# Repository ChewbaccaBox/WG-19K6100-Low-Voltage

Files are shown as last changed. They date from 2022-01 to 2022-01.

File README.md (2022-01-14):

# WG-19K6100-Low-Voltage
My version of the low voltage replacement board for the 6100 monitor.\
Larger / Through-hole parts provide beter thermals.\
Adjustable voltage range = +/- 23.5v - 28.5v \
&nbsp;

**BILL OF MATERIALS** :\
Includes example digikey item #'s

**1 * LM317 ( TO-220 pkg.)**\
&nbsp;&nbsp;&nbsp;&nbsp; DGK: LM317TG \
**1 * LM337 ( TO-220 pkg.)**\
&nbsp;&nbsp;&nbsp;&nbsp; DGK: LM3137TG \
**2 * 1k Trimmer Pot (PCB can fit both '.' and ... pin types, 0.1" spacing)**\
&nbsp;&nbsp;&nbsp;&nbsp; DGK: 500E-0331 or DGK:3306W-1-102\
**6 * 1N4007 Diode**\
**4 * 2.2uF 50V Capacitor**\
**2 * 10uF 50V Capacitor**\
**2 * 240 Ohm Resistor 1/4W**\
**4 * 4.5k Ohm Resistor 1/4W**\
**5 * WIRES TO RAISE PCB OVER BOARD**

**(OPTIONAL) 2 * TO-220 Compact Heatsink + Insulator/Thermal Pad** \
&nbsp;&nbsp;&nbsp;&nbsp; DGK: 577102B00000G + SP400-0.007-00-54 \
&nbsp;

**TESTING STATUS:**

Multiple installed and working in revisions P314 and P327.\
The filter capicators of the deflection board are closer to the connector on revision P327, so it is a little tighter, but will still work.

**INSTALLATION INSTRUCTIONS:**

To be written... Stay tuned!

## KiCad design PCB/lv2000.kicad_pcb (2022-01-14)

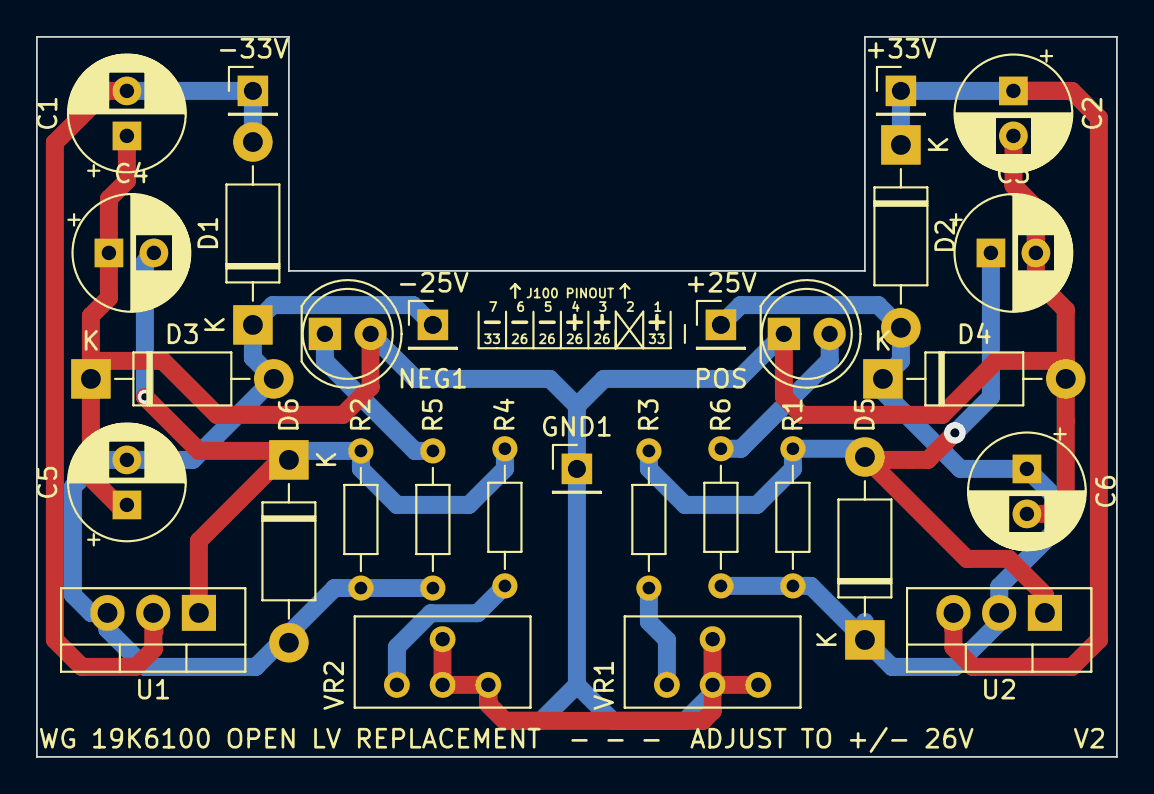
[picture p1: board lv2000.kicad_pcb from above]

Board: 2 copper layers, 60.0 x 40.0 mm, 29 parts (0 on the bottom side), 11 nets.

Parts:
+25V, +33V: Conn_01x01_Male; PinHeader_1x01_P2.54mm_Vertical
-25V, -33V: Conn_01x01_Male; PinHeader_1x01_P2.54mm_Vertical
C1, C2, C3, C4, C5, C6: CP; CP_Radial_D6.3mm_P2.50mm
D1, D2, D3, D4, D5, D6: D; D_DO-41_SOD81_P10.16mm_Horizontal
GND1: Conn_01x01_Male; PinHeader_1x01_P2.54mm_Vertical
NEG1: LED; LED_D5.0mm_Clear
POS: LED; LED_D5.0mm_Clear
R1, R2, R3, R4, R5, R6: R; R_Axial_DIN0204_L3.6mm_D1.6mm_P7.62mm_Horizontal
U1: LM337_TO220; TO-220-3_Vertical
U2: LM317_TO-220; TO-220-3_Vertical
VR1, VR2: R_POT; Potentiometer_Bourns_3386C_Horizontal

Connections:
GND: C1.1, C2.2, C3.2, C4.1, C5.1, C6.2, D3.1, D4.2, GND1.1, NEG1.2, POS.1, VR1.2, VR1.3, VR2.2, VR2.3
unnamed: +25V.1, C6.1, D2.2, D4.1, D5.1, R1.1, R6.1, U2.2
unnamed: +33V.1, C2.1, D2.1, U2.3
unnamed: -25V.1, C5.2, D1.1, D3.2, D6.2, R2.2, R5.2, U1.3
unnamed: -33V.1, C1.2, D1.2, U1.2
unnamed: C3.1, D5.2, R1.2, R3.1, U2.1
unnamed: C4.2, D6.1, R2.1, R4.2, U1.1
unnamed: NEG1.1, R5.1
unnamed: POS.2, R6.2
unnamed: R3.2, VR1.1
unnamed: R4.1, VR2.1

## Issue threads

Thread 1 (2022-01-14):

Doesn't fit as well on P327 revisions of the deflection board.

ChewbaccaBox, 2022-01-14:
The LV section is laid out differently; closer to the large filter capacitors, which means you have to angle the LV board at an odd angle to be able to plug the transistor connector in.

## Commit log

2022-01-14 First commit
    need to organize and update
    [lv2000.kicad_pcb, lv2000.sch]
2022-01-14 Create PCB
2022-01-14 Delete PCB
    didn't mean to
2022-01-14 Rename lv2000-cache.lib to PCB/lv2000-cache.lib
    Move to PCB folder
2022-01-14 Rename lv2000.kicad_pcb to PCB/lv2000.kicad_pcb
    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
    [lv2000.kicad_pcb]
2022-01-14 Rename lv2000.kicad_pcb-bak to PCB/lv2000.kicad_pcb-bak
    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
2022-01-14 Rename lv2000.pro to PCB/lv2000.pro
    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
2022-01-14 Rename lv2000.sch to PCB/lv2000.sch
    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
    [lv2000.sch]
2022-01-14 Rename lv2000.sch-bak to PCB/lv2000.sch-bak
    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
